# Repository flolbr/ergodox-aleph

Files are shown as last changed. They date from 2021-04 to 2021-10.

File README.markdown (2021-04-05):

# Ergodox Aleph 1

Please note that this project uses the nightly version of KiCad (or Kicad 6).

Ergodox [Aleph 1][aleph] is a modification of the [Ergodox Infinity][original].

Major changes include:

* Full Under-Key RGB
* Through-hole diodes for easy soldering
* Replaced the expensive J-Link Needle port with a cheaper J-Link socket
* RGB header for optional underglow
* Added stabiliser holes to 2U keys on thumb cluster
* Replaced discontinued USB ports with new parts

**I've only done the left board so far.**

[aleph]: https://en.wikipedia.org/wiki/Aleph_number
[original]: https://input.club/devices/infinity-ergodox/

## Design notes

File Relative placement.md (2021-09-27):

Left (d=nok, led=ok):
D36:     (at 69.066497 132.373 180)
LED36: (at 72.241499 127.320001)
S36:      (at 72.241499 132.32 180)
led_x = s_x; led_y = s_y - 5

Right (d=ok, led=nok):
D36:     (at 145.478 140.028 180)
LED36: (at 148.6154 134.366)
S36:      (at 148.59 140.028 180)
d_x = s_x - 3.112; d_y = s_y

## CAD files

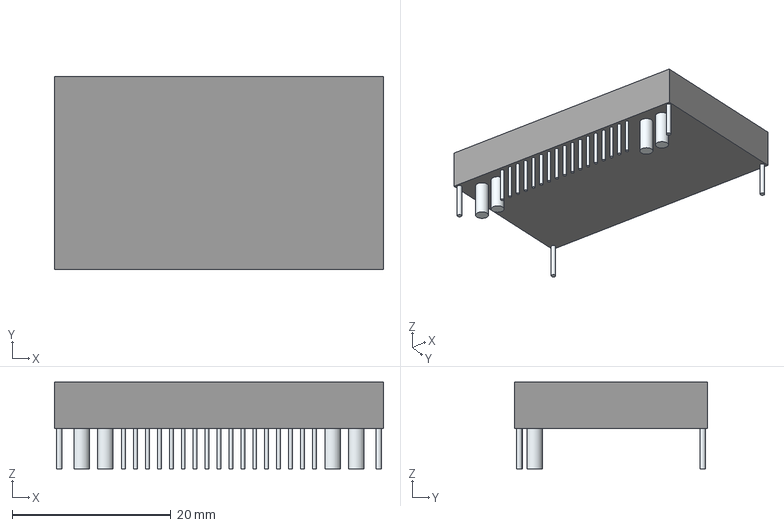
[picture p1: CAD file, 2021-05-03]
ICED - Left/alt3d/NHD-C12832A1Z-FS_RGB_-FBW-3V.stp
41.4 x 24.3 x 10.9 mm
Leads x 25

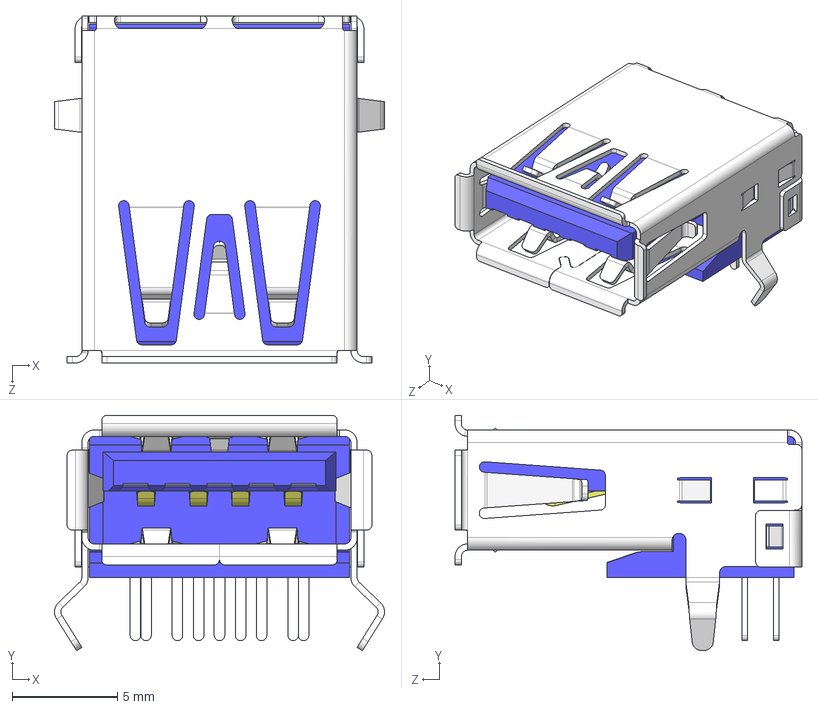
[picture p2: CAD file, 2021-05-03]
ICED - Left/alt3d/CUI_DEVICES_UJ3-AH-4-TH.step
15.7 x 11.2 x 16.5 mm

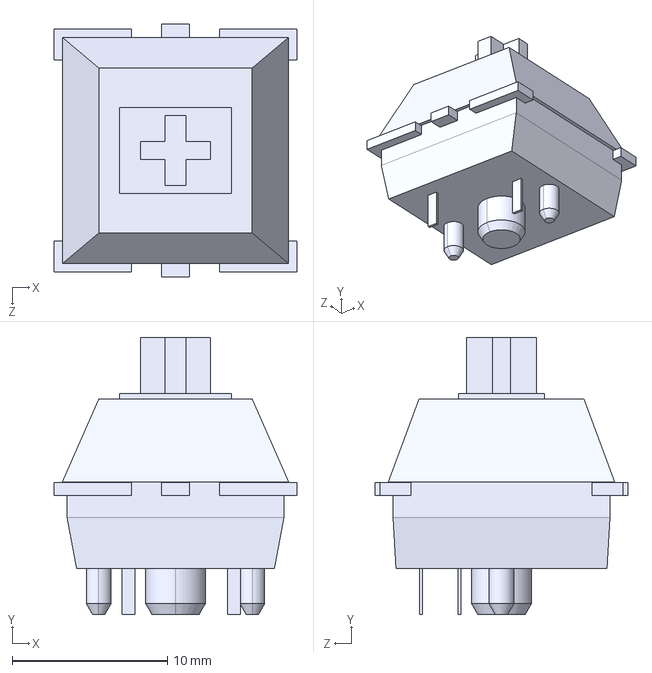
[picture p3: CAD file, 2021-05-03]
ICED - Left/alt3d/cherry mx.STEP
15.6 x 17.9 x 16.3 mm

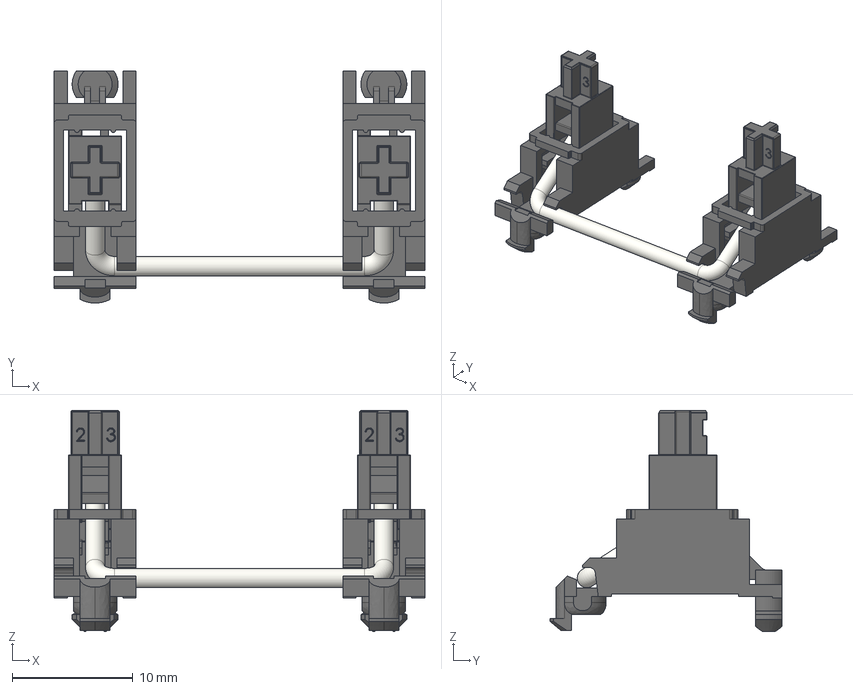
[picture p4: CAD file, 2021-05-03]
ICED - Left/alt3d/Stabilizer_Cherry_MX_2u.step
30.7 x 19.2 x 18.3 mm

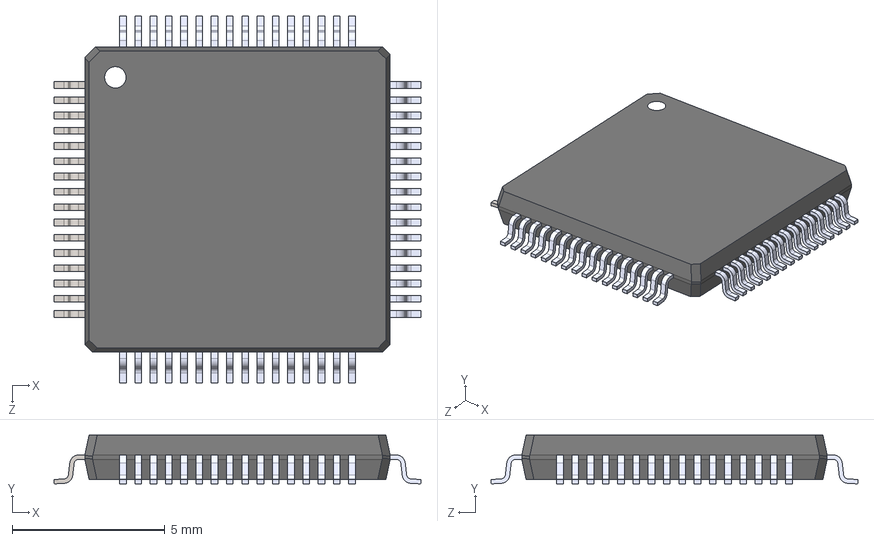
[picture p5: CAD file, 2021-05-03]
ICED - Left/alt3d/MK20DX256VLH7--3DModel-STEP-56544.STEP
12.0 x 1.60 x 12.0 mm

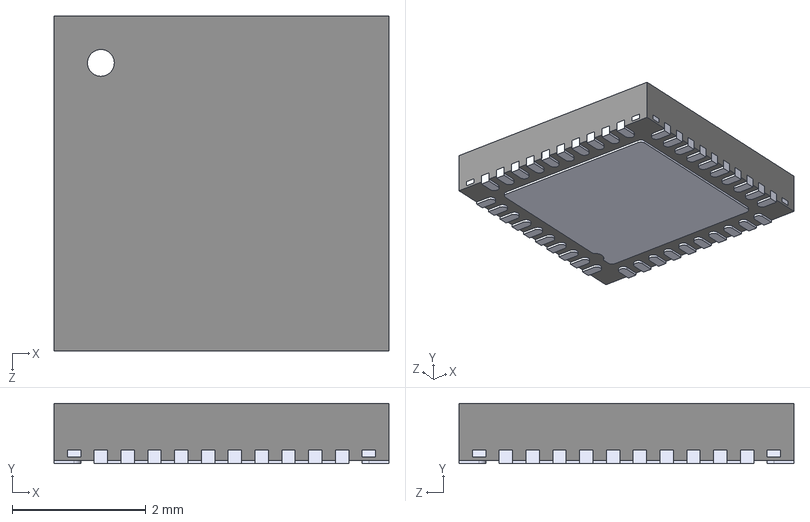
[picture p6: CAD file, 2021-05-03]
ICED - Left/alt3d/DA14586-00F02AT2.STEP
5.00 x 0.9 x 5.00 mm

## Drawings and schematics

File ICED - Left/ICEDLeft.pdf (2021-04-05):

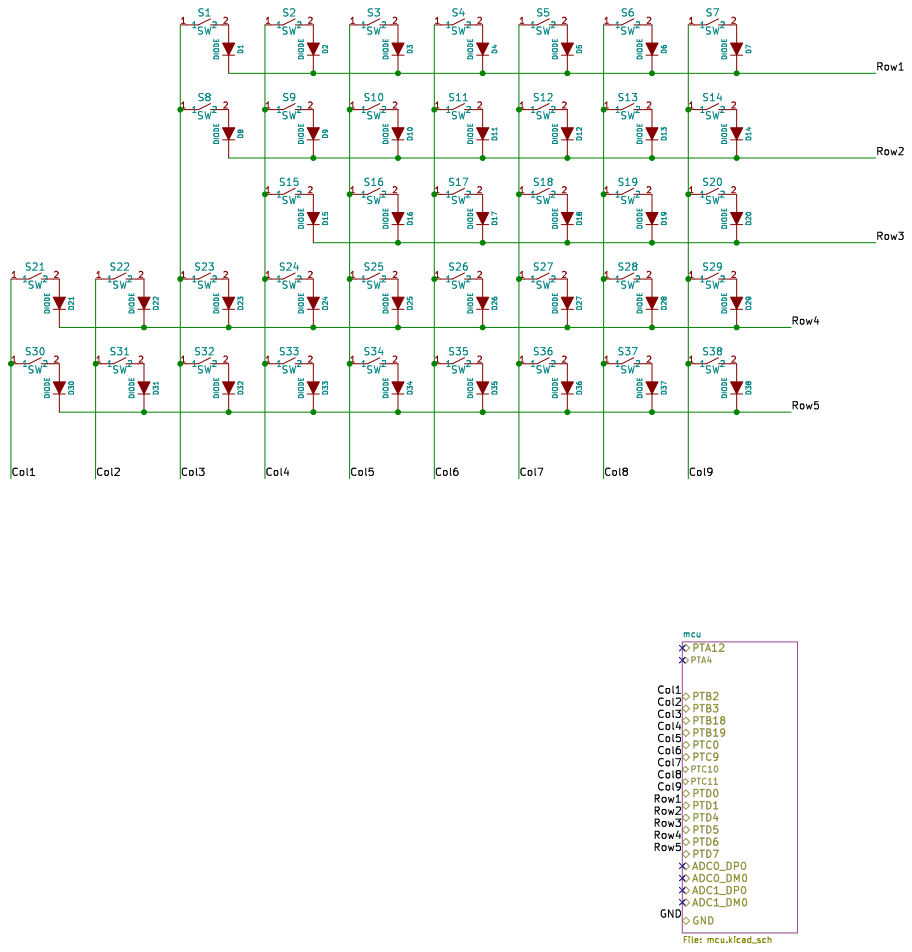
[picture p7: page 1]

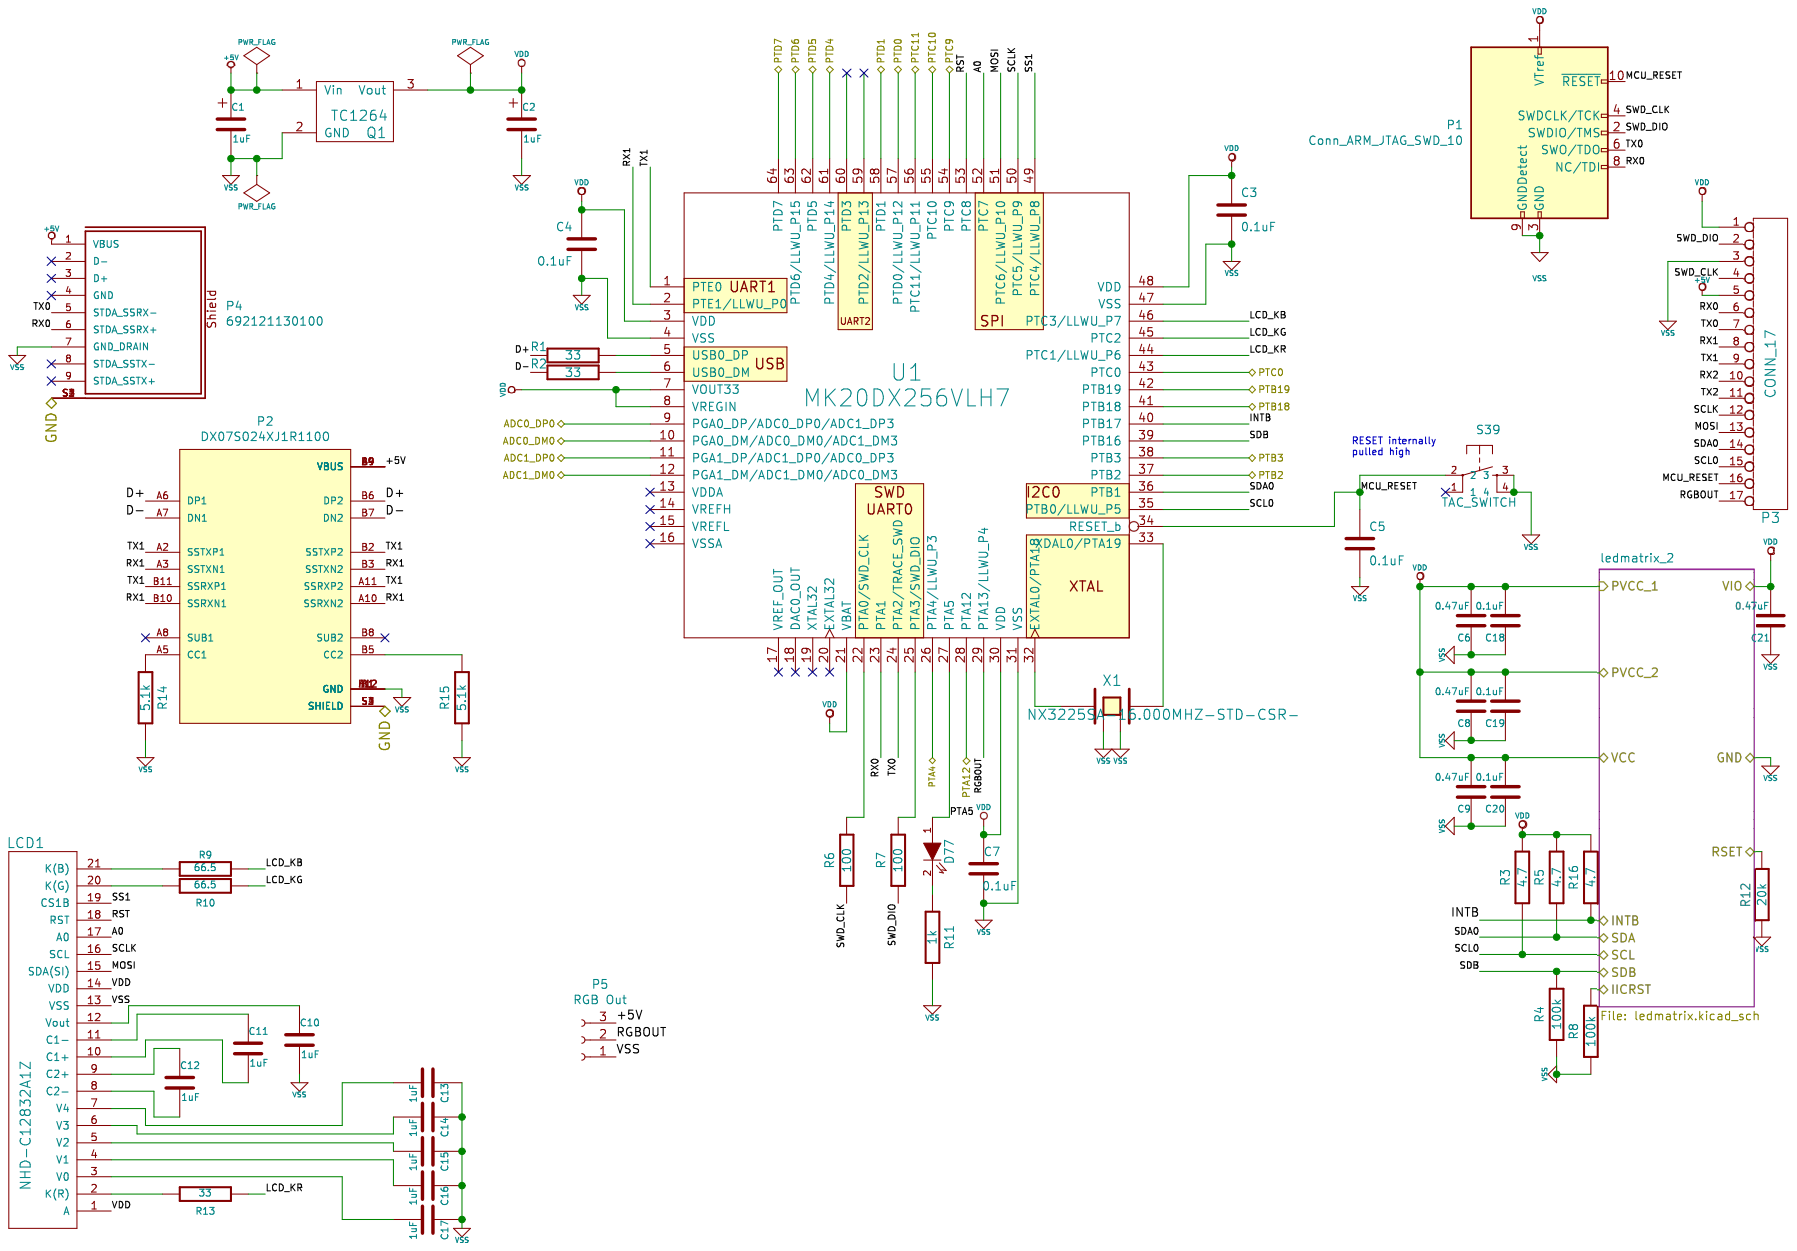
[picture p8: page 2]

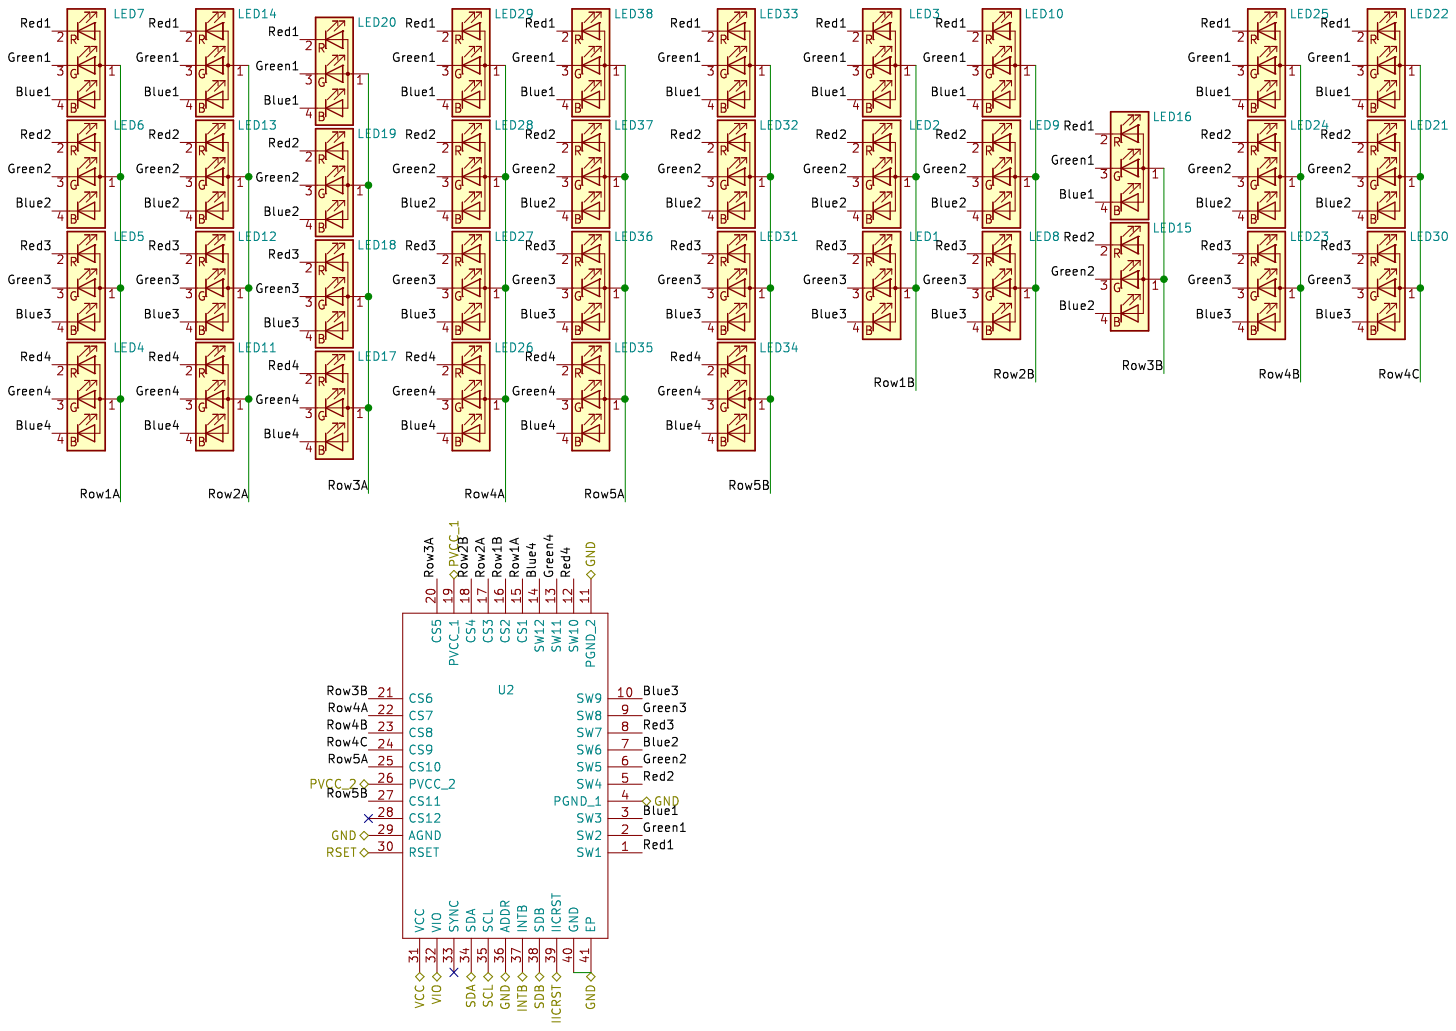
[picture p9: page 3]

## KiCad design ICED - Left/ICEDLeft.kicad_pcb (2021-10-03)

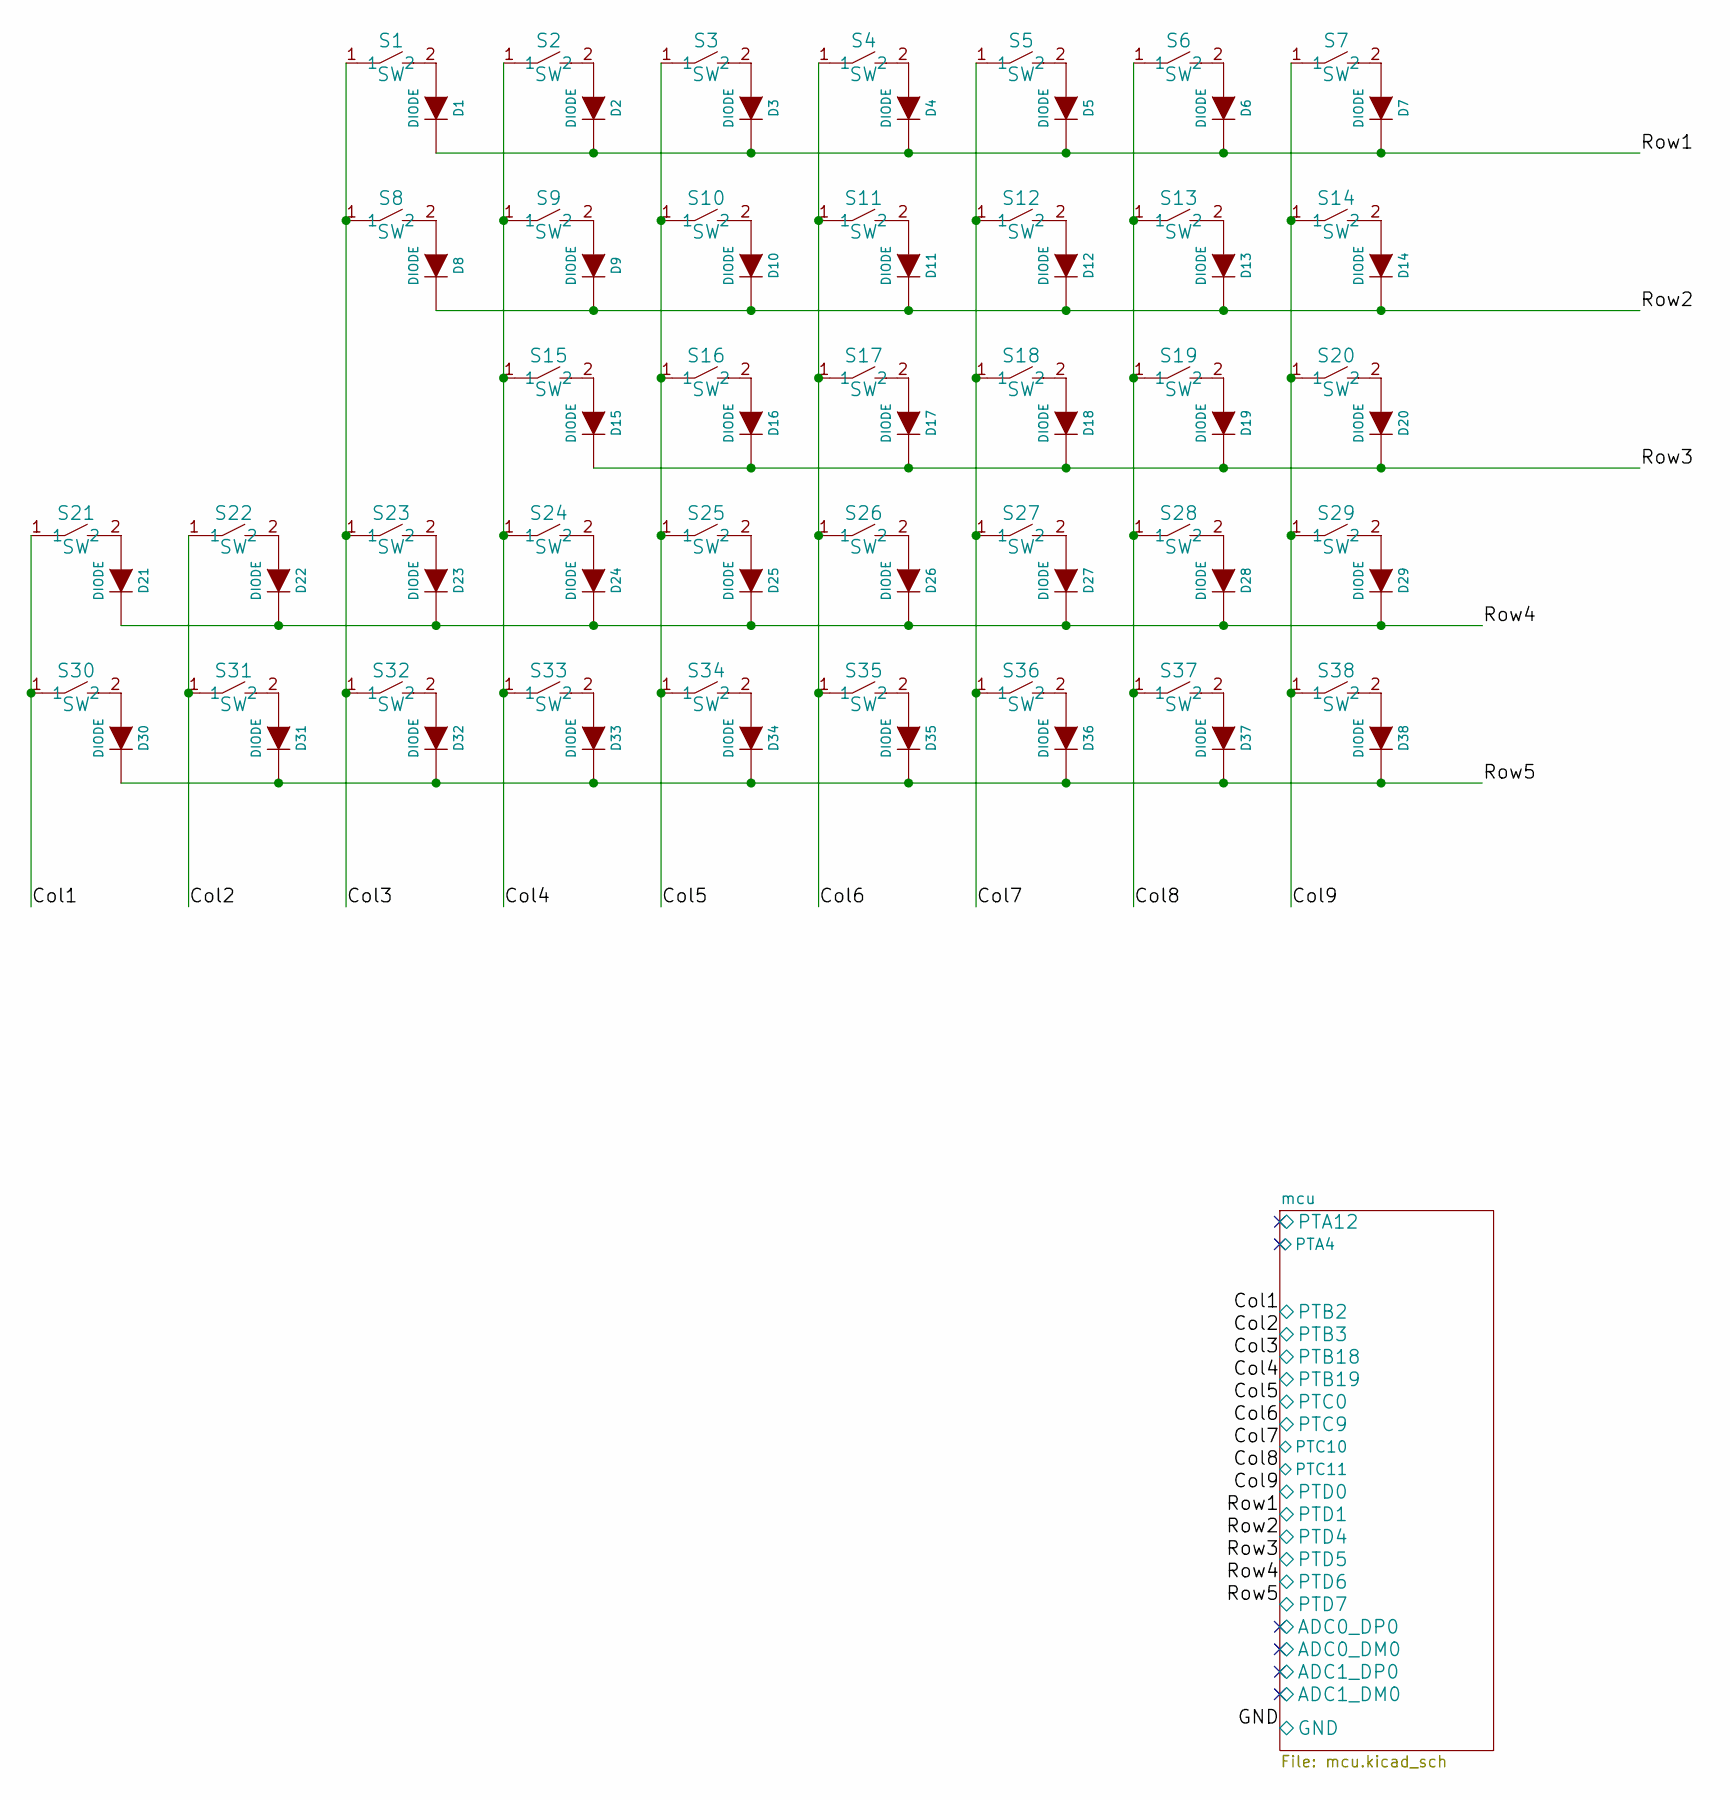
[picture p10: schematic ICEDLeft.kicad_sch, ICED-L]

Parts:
D1, D2, D3, D4, D5, D6, D7, D8, D9, D10, D11, D12, D13, D14, D15, D16, D17, D18, D19, D20, D21, D22, D23, D24, D25, D26, D27, D28, D29, D30, D31, D32, D33, D34, D35, D36, D37, D38: DIODE; SOT123-DIODE
S1, S2, S3, S4, S5, S6, S7, S8, S9, S10, S11, S12, S13, S14, S15, S16, S17, S18, S19, S20, S21, S22, S23, S24, S25, S26, S27, S28, S29, S30, S31, S32, S33, S34, S35, S36, S37, S38: SW; SW_Hotswap_Kailh

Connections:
/Col1: S21.1, S30.1; also elsewhere on the board
/Col2: S22.1, S31.1; also elsewhere on the board
/Col3: S1.1, S8.1, S23.1, S32.1; also elsewhere on the board
/Col4: S2.1, S9.1, S15.1, S24.1, S33.1; also elsewhere on the board
/Col5: S3.1, S10.1, S16.1, S25.1, S34.1; also elsewhere on the board
/Col6: S4.1, S11.1, S17.1, S26.1, S35.1; also elsewhere on the board
/Col7: S5.1, S12.1, S18.1, S27.1, S36.1; also elsewhere on the board
/Col8: S6.1, S13.1, S19.1, S28.1, S37.1; also elsewhere on the board
/Col9: S7.1, S14.1, S20.1, S29.1, S38.1; also elsewhere on the board
/Row1: D1.2 (K), D2.2 (K), D3.2 (K), D4.2 (K), D5.2 (K), D6.2 (K), D7.2 (K); also elsewhere on the board
/Row2: D8.2 (K), D9.2 (K), D10.2 (K), D11.2 (K), D12.2 (K), D13.2 (K), D14.2 (K); also elsewhere on the board
/Row3: D15.2 (K), D16.2 (K), D17.2 (K), D18.2 (K), D19.2 (K), D20.2 (K); also elsewhere on the board
/Row4: D21.2 (K), D22.2 (K), D23.2 (K), D24.2 (K), D25.2 (K), D26.2 (K), D27.2 (K), D28.2 (K), D29.2 (K); also elsewhere on the board
/Row5: D30.2 (K), D31.2 (K), D32.2 (K), D33.2 (K), D34.2 (K), D35.2 (K), D36.2 (K), D37.2 (K), D38.2 (K); also elsewhere on the board
unnamed: D1.1 (A), S1.2
unnamed: D2.1 (A), S2.2
unnamed: D3.1 (A), S3.2
unnamed: D4.1 (A), S4.2
unnamed: D5.1 (A), S5.2
unnamed: D6.1 (A), S6.2
unnamed: D7.1 (A), S7.2
unnamed: D8.1 (A), S8.2
unnamed: D9.1 (A), S9.2
unnamed: D10.1 (A), S10.2
unnamed: D11.1 (A), S11.2
unnamed: D12.1 (A), S12.2
unnamed: D13.1 (A), S13.2
unnamed: D14.1 (A), S14.2
unnamed: D15.1 (A), S15.2
unnamed: D16.1 (A), S16.2
unnamed: D17.1 (A), S17.2
unnamed: D18.1 (A), S18.2
unnamed: D19.1 (A), S19.2
unnamed: D20.1 (A), S20.2
unnamed: D21.1 (A), S21.2
unnamed: D22.1 (A), S22.2
unnamed: D23.1 (A), S23.2
unnamed: D24.1 (A), S24.2
unnamed: D25.1 (A), S25.2
unnamed: D26.1 (A), S26.2
unnamed: D27.1 (A), S27.2
unnamed: D28.1 (A), S28.2
unnamed: D29.1 (A), S29.2
unnamed: D30.1 (A), S30.2
unnamed: D31.1 (A), S31.2
unnamed: D32.1 (A), S32.2
unnamed: D33.1 (A), S33.2
unnamed: D34.1 (A), S34.2
unnamed: D35.1 (A), S35.2
unnamed: D36.1 (A), S36.2
unnamed: D37.1 (A), S37.2
unnamed: D38.1 (A), S38.2

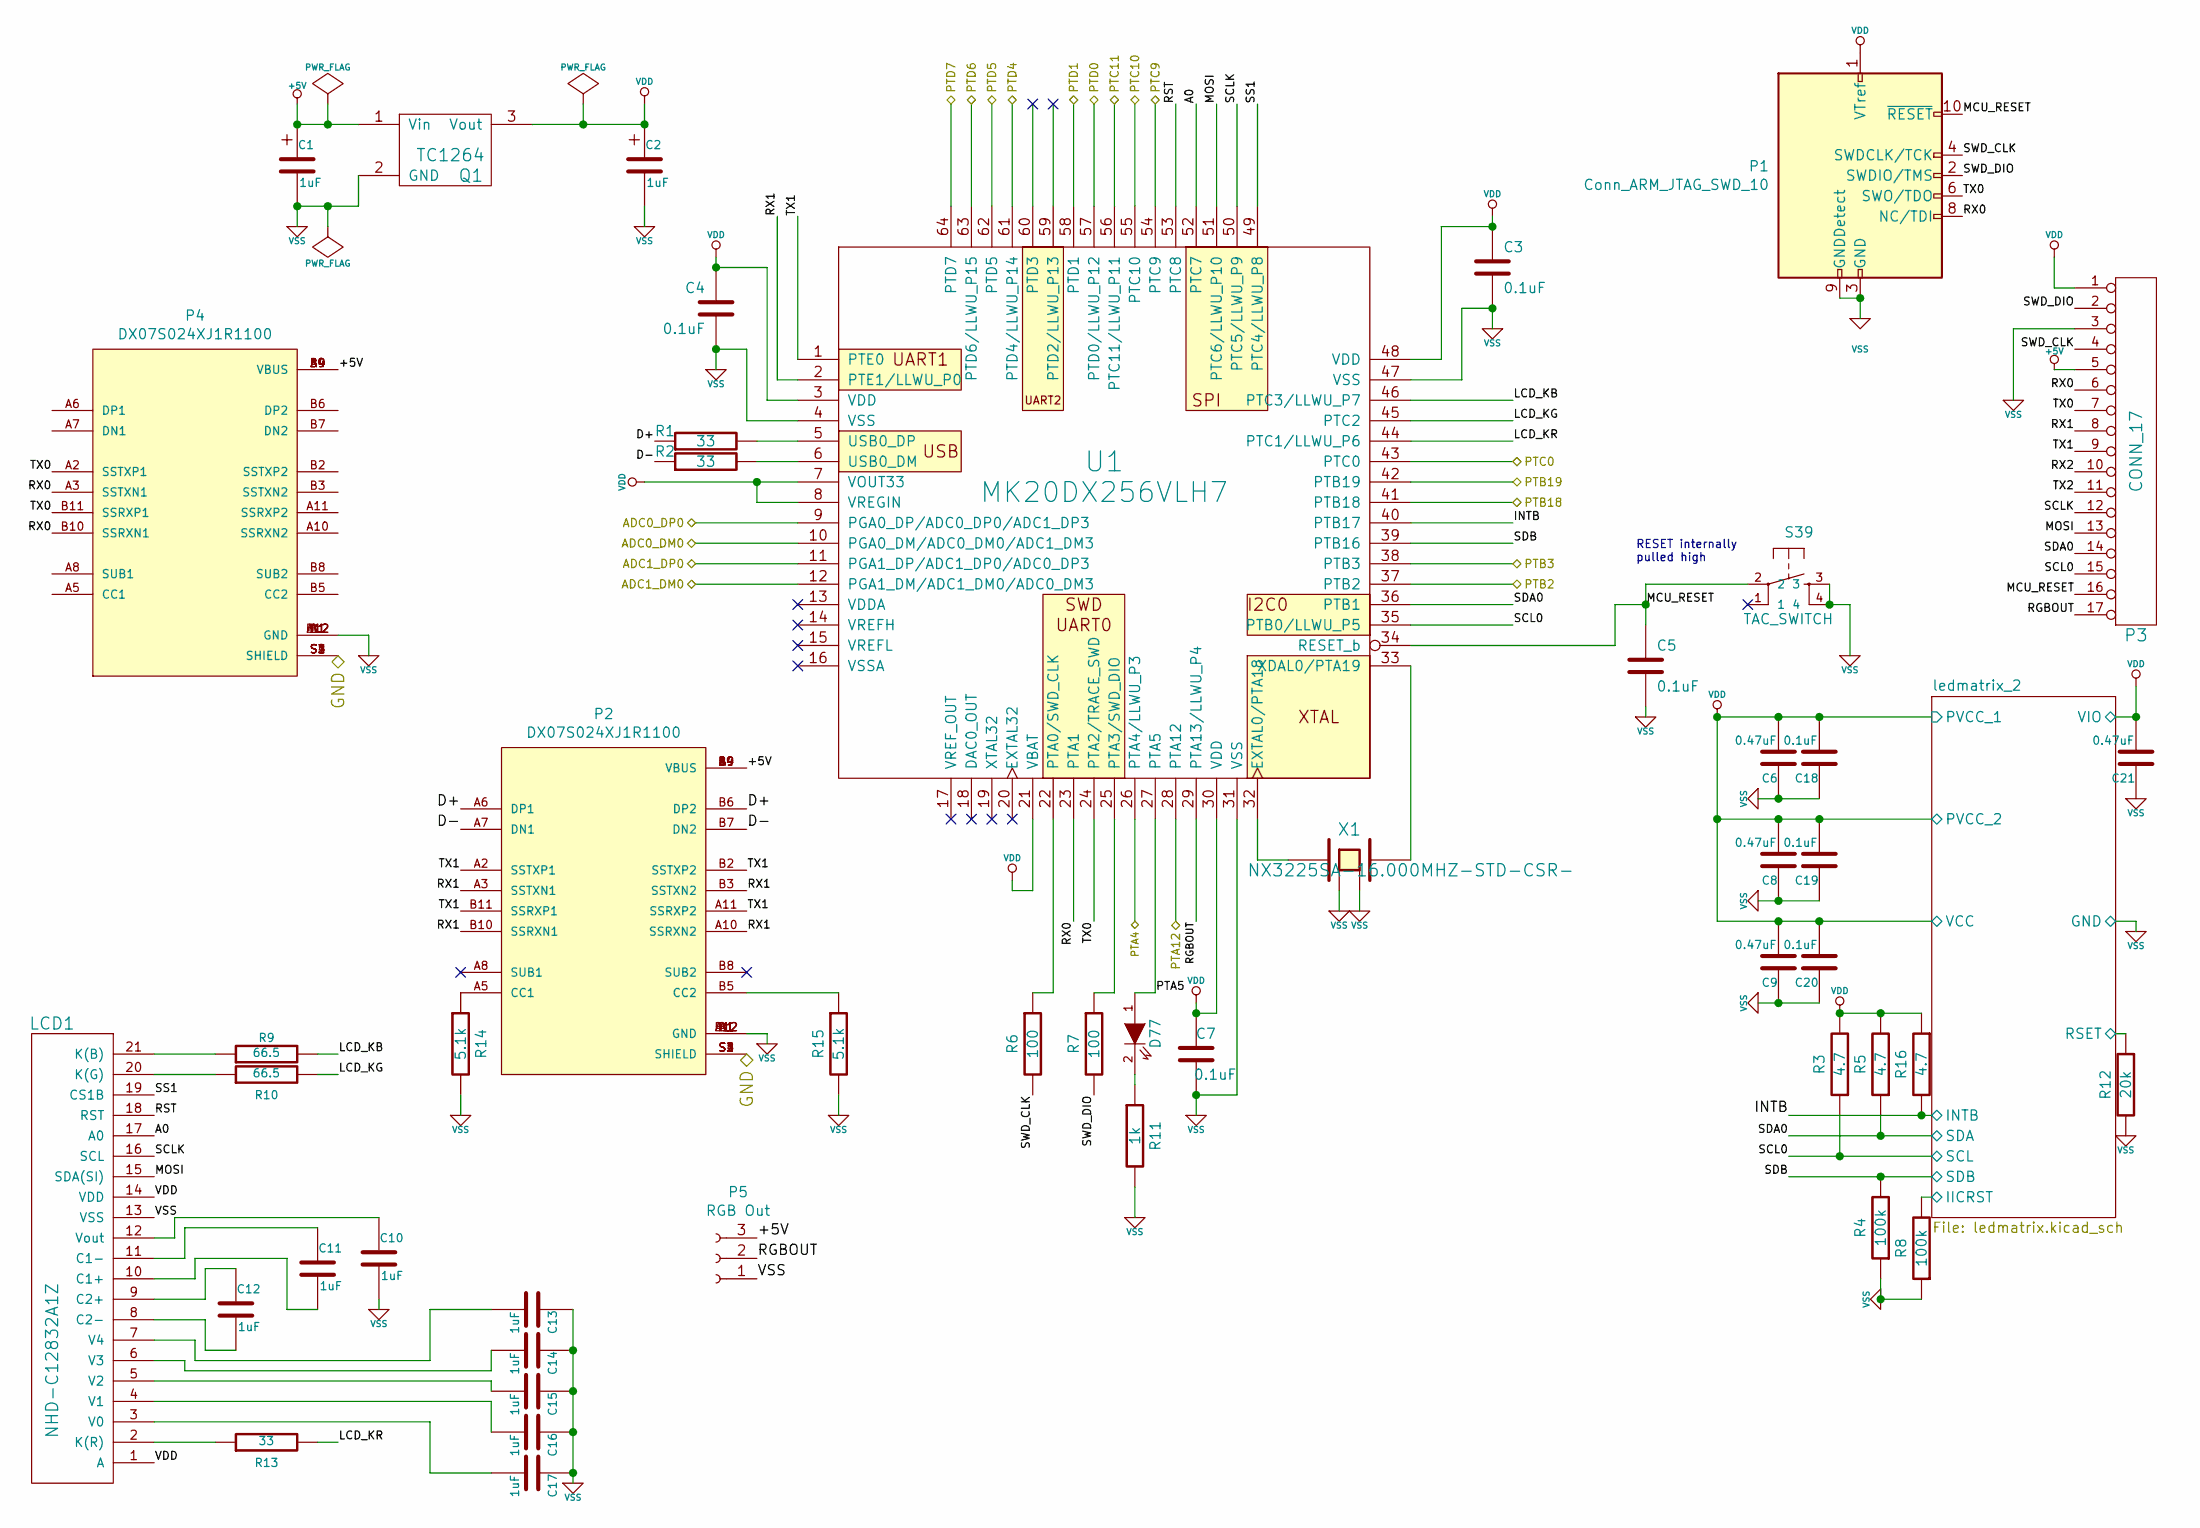
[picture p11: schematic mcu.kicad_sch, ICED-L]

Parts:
C1, C2, C10, C11, C12, C13, C14, C15, C16, C17: 1uF; SMD-1005
C3, C4, C5, C7, C18, C19, C20: 0.1uF; SMD-1005
C6, C8, C9, C21: 0.47uF; SMD-1005
D77: LED; LED-0603
LCD1: NHD-C12832A1Z
P1: Conn_ARM_JTAG_SWD_10; SHF-105-01-L-D-TH
P2, P4: DX07S024XJ1R1100; JAE_DX07S024XJ1R1100; PARTREV 1
P3: CONN_17; HEADER_1x17
P5: RGB Out; PinHeader_1x03_P2.54mm_Horizontal
Q1: TC1264; SOT-223
R1, R2, R13: 33; SMD-1005
R3, R5, R16: 4.7; SMD-1005
R4, R8: 100k; SMD-1005
R6, R7: 100; SMD-1005
R9, R10: 66.5; SMD-1005
R11: 1k; SMD-1005
R12: 20k; SMD-1005
R14, R15: 5.1k; SMD-1005
S39: TAC_SWITCH; TACT_5.2x5.2
U1: MK20DX256VLH7; LQFP64
X1: NX3225SA-16.000MHZ-STD-CSR-; NX3225SA

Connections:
+5V: C1.1, P2.A4 (VBUS), P2.A9 (VBUS), P2.B4 (VBUS), P2.B9 (VBUS), P3.5, P4.A4 (VBUS), P4.A9 (VBUS), P4.B4 (VBUS), P4.B9 (VBUS), P5.3, Q1.1 (Vin)
/Col1: U1.37 (PTB2); also elsewhere on the board
/Col2: U1.38 (PTB3); also elsewhere on the board
/Col3: U1.41 (PTB18); also elsewhere on the board
/Col4: U1.42 (PTB19); also elsewhere on the board
/Col5: U1.43 (PTC0); also elsewhere on the board
/Col6: U1.54 (PTC9); also elsewhere on the board
/Col7: U1.55 (PTC10); also elsewhere on the board
/Col8: U1.56 (PTC11/LLWU_P11); also elsewhere on the board
/Col9: U1.57 (PTD0/LLWU_P12); also elsewhere on the board
/GND: P2.S1 (SHIELD), P2.S2 (SHIELD), P2.S3 (SHIELD), P2.S4 (SHIELD), P4.S1 (SHIELD), P4.S2 (SHIELD), P4.S3 (SHIELD), P4.S4 (SHIELD)
/Row1: U1.58 (PTD1); also elsewhere on the board
/Row2: U1.61 (PTD4/LLWU_P14); also elsewhere on the board
/Row3: U1.62 (PTD5); also elsewhere on the board
/Row4: U1.63 (PTD6/LLWU_P15); also elsewhere on the board
/Row5: U1.64 (PTD7); also elsewhere on the board
/mcu/A0: LCD1.17 (A0), U1.52 (PTC7)
/mcu/ADC0_DM0: U1.10 (PGA0_DM/ADC0_DM0/ADC1_DM3)
/mcu/ADC0_DP0: U1.9 (PGA0_DP/ADC0_DP0/ADC1_DP3)
/mcu/ADC1_DM0: U1.12 (PGA1_DM/ADC1_DM0/ADC0_DM3)
/mcu/ADC1_DP0: U1.11 (PGA1_DP/ADC1_DP0/ADC0_DP3)
/mcu/D+: P2.A6 (DP1), P2.B6 (DP2), R1.1
/mcu/D-: P2.A7 (DN1), P2.B7 (DN2), R2.1
/mcu/INTB: R16.2, U1.40 (PTB17); also elsewhere on the board
/mcu/LCD_KB: R9.2, U1.46 (PTC3/LLWU_P7)
/mcu/LCD_KG: R10.2, U1.45 (PTC2)
/mcu/LCD_KR: R13.2, U1.44 (PTC1/LLWU_P6)
/mcu/MCU_RESET: C5.1, P1.10 (~RESET), P3.16, S39.2, U1.34 (RESET_b)
/mcu/MOSI: LCD1.15 (SDA(SI)), P3.13, U1.51 (PTC6/LLWU_P10)
/mcu/PTA4: U1.26 (PTA4/LLWU_P3)
/mcu/PTA5: D77.1 (A), U1.27 (PTA5)
/mcu/PTA12: U1.28 (PTA12)
/mcu/RGBOUT: P3.17, P5.2, U1.29 (PTA13/LLWU_P4)
/mcu/RST: LCD1.18 (RST), U1.53 (PTC8)
/mcu/RX0: P1.8 (NC/TDI), P3.6, P4.A3 (SSTXN1), P4.B10 (SSRXN1), U1.23 (PTA1)
/mcu/RX1: P2.A3 (SSTXN1), P2.A10 (SSRXN2), P2.B3 (SSTXN2), P2.B10 (SSRXN1), P3.8, U1.2 (PTE1/LLWU_P0)
/mcu/RX2: P3.10
/mcu/SCL0: P3.15, R3.1, U1.35 (PTB0/LLWU_P5); also elsewhere on the board
/mcu/SCLK: LCD1.16 (SCL), P3.12, U1.50 (PTC5/LLWU_P9)
/mcu/SDA0: P3.14, R5.1, U1.36 (PTB1); also elsewhere on the board
/mcu/SDB: R4.2, U1.39 (PTB16); also elsewhere on the board
/mcu/SS1: LCD1.19 (CS1B), U1.49 (PTC4/LLWU_P8)
/mcu/SWD_CLK: P1.4 (SWDCLK/TCK), P3.4, R6.2
/mcu/SWD_DIO: P1.2 (SWDIO/TMS), P3.2, R7.2
/mcu/TX0: P1.6 (SWO/TDO), P3.7, P4.A2 (SSTXP1), P4.B11 (SSRXP1), U1.24 (PTA2/TRACE_SWD)
/mcu/TX1: P2.A2 (SSTXP1), P2.A11 (SSRXP2), P2.B2 (SSTXP2), P2.B11 (SSRXP1), P3.9, U1.1 (PTE0)
/mcu/TX2: P3.11
/mcu/ledmatrix_2/IICRST: R8.2; also elsewhere on the board
/mcu/ledmatrix_2/RSET: R12.1; also elsewhere on the board
unnamed: C10.1, LCD1.12 (Vout)
unnamed: C11.1, LCD1.11 (C1-)
unnamed: C11.2, LCD1.10 (C1+)
unnamed: C12.1, LCD1.9 (C2+)
unnamed: C12.2, LCD1.8 (C2-)
unnamed: C13.2, LCD1.7 (V4)
unnamed: C14.2, LCD1.6 (V3)
unnamed: C15.2, LCD1.5 (V2)
unnamed: C16.2, LCD1.4 (V1)
unnamed: C17.2, LCD1.3 (V0)
unnamed: D77.2 (K), R11.1
unnamed: LCD1.2 (K(R)), R13.1
unnamed: LCD1.20 (K(G)), R10.1
unnamed: LCD1.21 (K(B)), R9.1
unnamed: R1.2, U1.5 (USB0_DP)
unnamed: R2.2, U1.6 (USB0_DM)
unnamed: R6.1, U1.22 (PTA0/SWD_CLK)
unnamed: R7.1, U1.25 (PTA3/SWD_DIO)
unnamed: P2.A5 (CC1), R14.1
unnamed: P2.B5 (CC2), R15.1
unnamed: U1.32 (EXTAL0/PTA18), X1.1
unnamed: U1.33 (XDAL0/PTA19), X1.3
VDD: C2.1, C3.1, C4.1, C6.2, C7.1, C8.2, C9.2, C18.2, C19.2, C20.2, C21.2, LCD1.1 (A), LCD1.14 (VDD), P1.1 (VTref), P3.1, Q1.3 (Vout), R3.2, R5.2, R16.1, U1.3 (VDD), U1.7 (VOUT33), U1.8 (VREGIN), U1.21 (VBAT), U1.30 (VDD), U1.48 (VDD); also elsewhere on the board
VSS: C1.2, C2.2, C3.2, C4.2, C5.2, C6.1, C7.2, C8.1, C9.1, C10.2, C13.1, C14.1, C15.1, C16.1, C17.1, C18.1, C19.1, C20.1, C21.1, LCD1.13 (VSS), P1.3 (GND), P1.5 (GND), P1.9 (GNDDetect), P2.A1 (GND), P2.A12 (GND), P2.B1 (GND), P2.B12 (GND), P3.3, P4.A1 (GND), P4.A12 (GND), P4.B1 (GND), P4.B12 (GND), P5.1, Q1.2 (GND), R4.1, R8.1, R11.2, R12.2, R14.2, R15.2, S39.3, S39.4, U1.4 (VSS), U1.31 (VSS), U1.47 (VSS), X1.2, X1.4; also elsewhere on the board

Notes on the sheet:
RESET internally pulled high

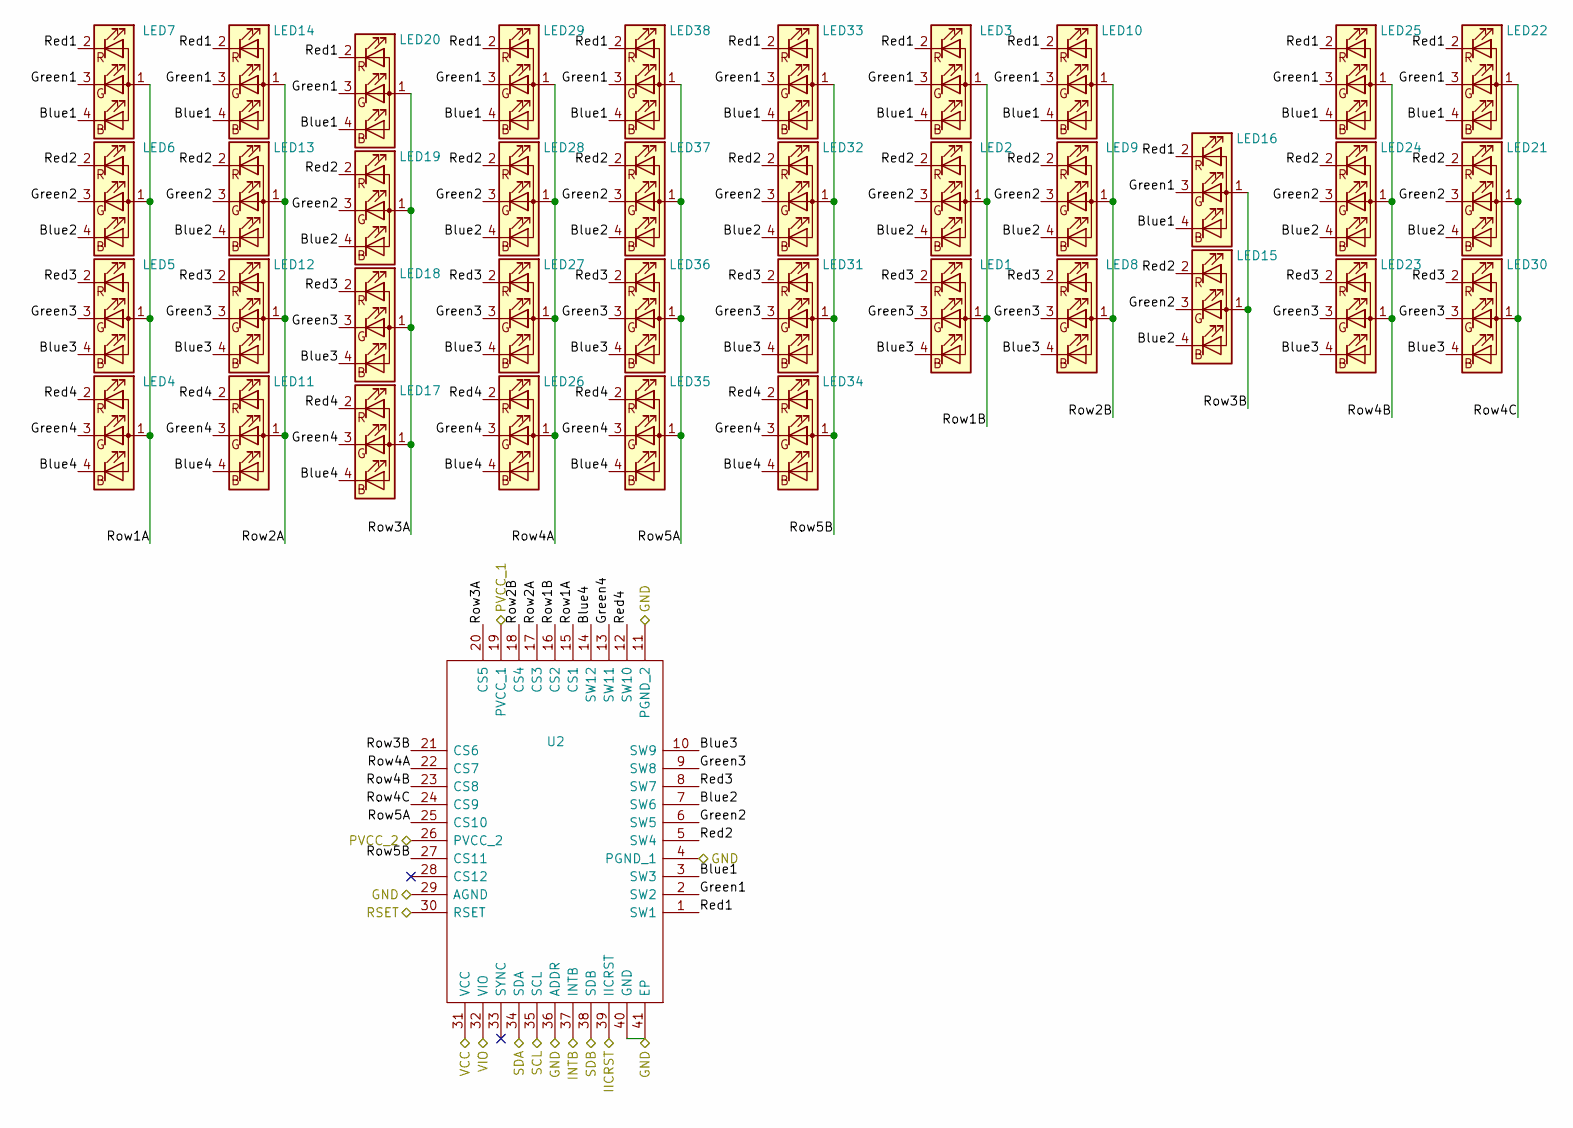
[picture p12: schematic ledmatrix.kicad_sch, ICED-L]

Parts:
LED1, LED2, LED3, LED4, LED5, LED6, LED7, LED8, LED9, LED10, LED11, LED12, LED13, LED14, LED15, LED16, LED17, LED18, LED19, LED20, LED21, LED22, LED23, LED24, LED25, LED26, LED27, LED28, LED29, LED30, LED31, LED32, LED33, LED34, LED35, LED36, LED37, LED38: RGB_0606; 0606
U2: IS31FL3737-QFLS4-TR; QFN40P500X500X80-41N-D; Manufacturer_Part_Number IS31FL3737-QFLS4-TR; Mouser Part Number 870-31FL3737QFLS4TR

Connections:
/mcu/INTB: U2.37 (INTB); also elsewhere on the board
/mcu/SCL0: U2.35 (SCL); also elsewhere on the board
/mcu/SDA0: U2.34 (SDA); also elsewhere on the board
/mcu/SDB: U2.38 (SDB); also elsewhere on the board
/mcu/ledmatrix_2/Blue1: LED3.4 (BK), LED7.4 (BK), LED10.4 (BK), LED14.4 (BK), LED16.4 (BK), LED20.4 (BK), LED22.4 (BK), LED25.4 (BK), LED29.4 (BK), LED33.4 (BK), LED38.4 (BK), U2.3 (SW3)
/mcu/ledmatrix_2/Blue2: LED2.4 (BK), LED6.4 (BK), LED9.4 (BK), LED13.4 (BK), LED15.4 (BK), LED19.4 (BK), LED21.4 (BK), LED24.4 (BK), LED28.4 (BK), LED32.4 (BK), LED37.4 (BK), U2.7 (SW6)
/mcu/ledmatrix_2/Blue3: LED1.4 (BK), LED5.4 (BK), LED8.4 (BK), LED12.4 (BK), LED18.4 (BK), LED23.4 (BK), LED27.4 (BK), LED30.4 (BK), LED31.4 (BK), LED36.4 (BK), U2.10 (SW9)
/mcu/ledmatrix_2/Blue4: LED4.4 (BK), LED11.4 (BK), LED17.4 (BK), LED26.4 (BK), LED34.4 (BK), LED35.4 (BK), U2.14 (SW12)
/mcu/ledmatrix_2/Green1: LED3.3 (GK), LED7.3 (GK), LED10.3 (GK), LED14.3 (GK), LED16.3 (GK), LED20.3 (GK), LED22.3 (GK), LED25.3 (GK), LED29.3 (GK), LED33.3 (GK), LED38.3 (GK), U2.2 (SW2)
/mcu/ledmatrix_2/Green2: LED2.3 (GK), LED6.3 (GK), LED9.3 (GK), LED13.3 (GK), LED15.3 (GK), LED19.3 (GK), LED21.3 (GK), LED24.3 (GK), LED28.3 (GK), LED32.3 (GK), LED37.3 (GK), U2.6 (SW5)
/mcu/ledmatrix_2/Green3: LED1.3 (GK), LED5.3 (GK), LED8.3 (GK), LED12.3 (GK), LED18.3 (GK), LED23.3 (GK), LED27.3 (GK), LED30.3 (GK), LED31.3 (GK), LED36.3 (GK), U2.9 (SW8)
/mcu/ledmatrix_2/Green4: LED4.3 (GK), LED11.3 (GK), LED17.3 (GK), LED26.3 (GK), LED34.3 (GK), LED35.3 (GK), U2.13 (SW11)
/mcu/ledmatrix_2/IICRST: U2.39 (IICRST); also elsewhere on the board
/mcu/ledmatrix_2/RSET: U2.30 (RSET); also elsewhere on the board
/mcu/ledmatrix_2/Red1: LED3.2 (RK), LED7.2 (RK), LED10.2 (RK), LED14.2 (RK), LED16.2 (RK), LED20.2 (RK), LED22.2 (RK), LED25.2 (RK), LED29.2 (RK), LED33.2 (RK), LED38.2 (RK), U2.1 (SW1)
/mcu/ledmatrix_2/Red2: LED2.2 (RK), LED6.2 (RK), LED9.2 (RK), LED13.2 (RK), LED15.2 (RK), LED19.2 (RK), LED21.2 (RK), LED24.2 (RK), LED28.2 (RK), LED32.2 (RK), LED37.2 (RK), U2.5 (SW4)
/mcu/ledmatrix_2/Red3: LED1.2 (RK), LED5.2 (RK), LED8.2 (RK), LED12.2 (RK), LED18.2 (RK), LED23.2 (RK), LED27.2 (RK), LED30.2 (RK), LED31.2 (RK), LED36.2 (RK), U2.8 (SW7)
/mcu/ledmatrix_2/Red4: LED4.2 (RK), LED11.2 (RK), LED17.2 (RK), LED26.2 (RK), LED34.2 (RK), LED35.2 (RK), U2.12 (SW10)
/mcu/ledmatrix_2/Row1A: LED4.1 (A), LED5.1 (A), LED6.1 (A), LED7.1 (A), U2.15 (CS1)
/mcu/ledmatrix_2/Row1B: LED1.1 (A), LED2.1 (A), LED3.1 (A), U2.16 (CS2)
/mcu/ledmatrix_2/Row2A: LED11.1 (A), LED12.1 (A), LED13.1 (A), LED14.1 (A), U2.17 (CS3)
/mcu/ledmatrix_2/Row2B: LED8.1 (A), LED9.1 (A), LED10.1 (A), U2.18 (CS4)
/mcu/ledmatrix_2/Row3A: LED17.1 (A), LED18.1 (A), LED19.1 (A), LED20.1 (A), U2.20 (CS5)
/mcu/ledmatrix_2/Row3B: LED15.1 (A), LED16.1 (A), U2.21 (CS6)
/mcu/ledmatrix_2/Row4A: LED26.1 (A), LED27.1 (A), LED28.1 (A), LED29.1 (A), U2.22 (CS7)
/mcu/ledmatrix_2/Row4B: LED23.1 (A), LED24.1 (A), LED25.1 (A), U2.23 (CS8)
/mcu/ledmatrix_2/Row4C: LED21.1 (A), LED22.1 (A), LED30.1 (A), U2.24 (CS9)
/mcu/ledmatrix_2/Row5A: LED35.1 (A), LED36.1 (A), LED37.1 (A), LED38.1 (A), U2.25 (CS10)
/mcu/ledmatrix_2/Row5B: LED31.1 (A), LED32.1 (A), LED33.1 (A), LED34.1 (A), U2.27 (CS11)
VDD: U2.19 (PVCC_1), U2.26 (PVCC_2), U2.31 (VCC), U2.32 (VIO); also elsewhere on the board
VSS: U2.4 (PGND_1), U2.11 (PGND_2), U2.29 (AGND), U2.36 (ADDR), U2.40 (GND), U2.41 (EP); also elsewhere on the board

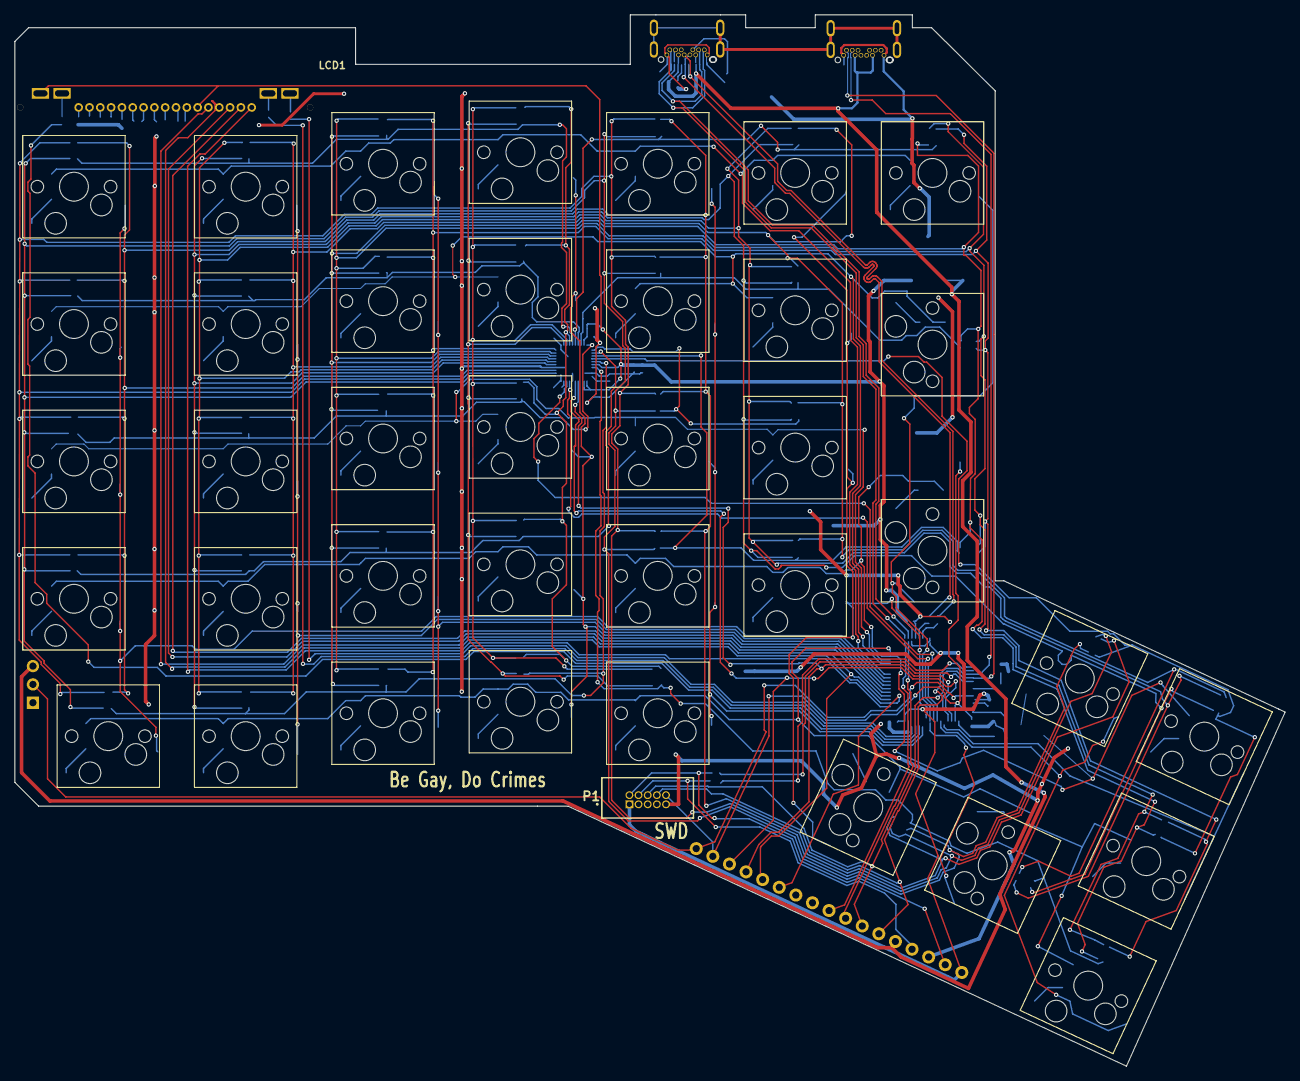
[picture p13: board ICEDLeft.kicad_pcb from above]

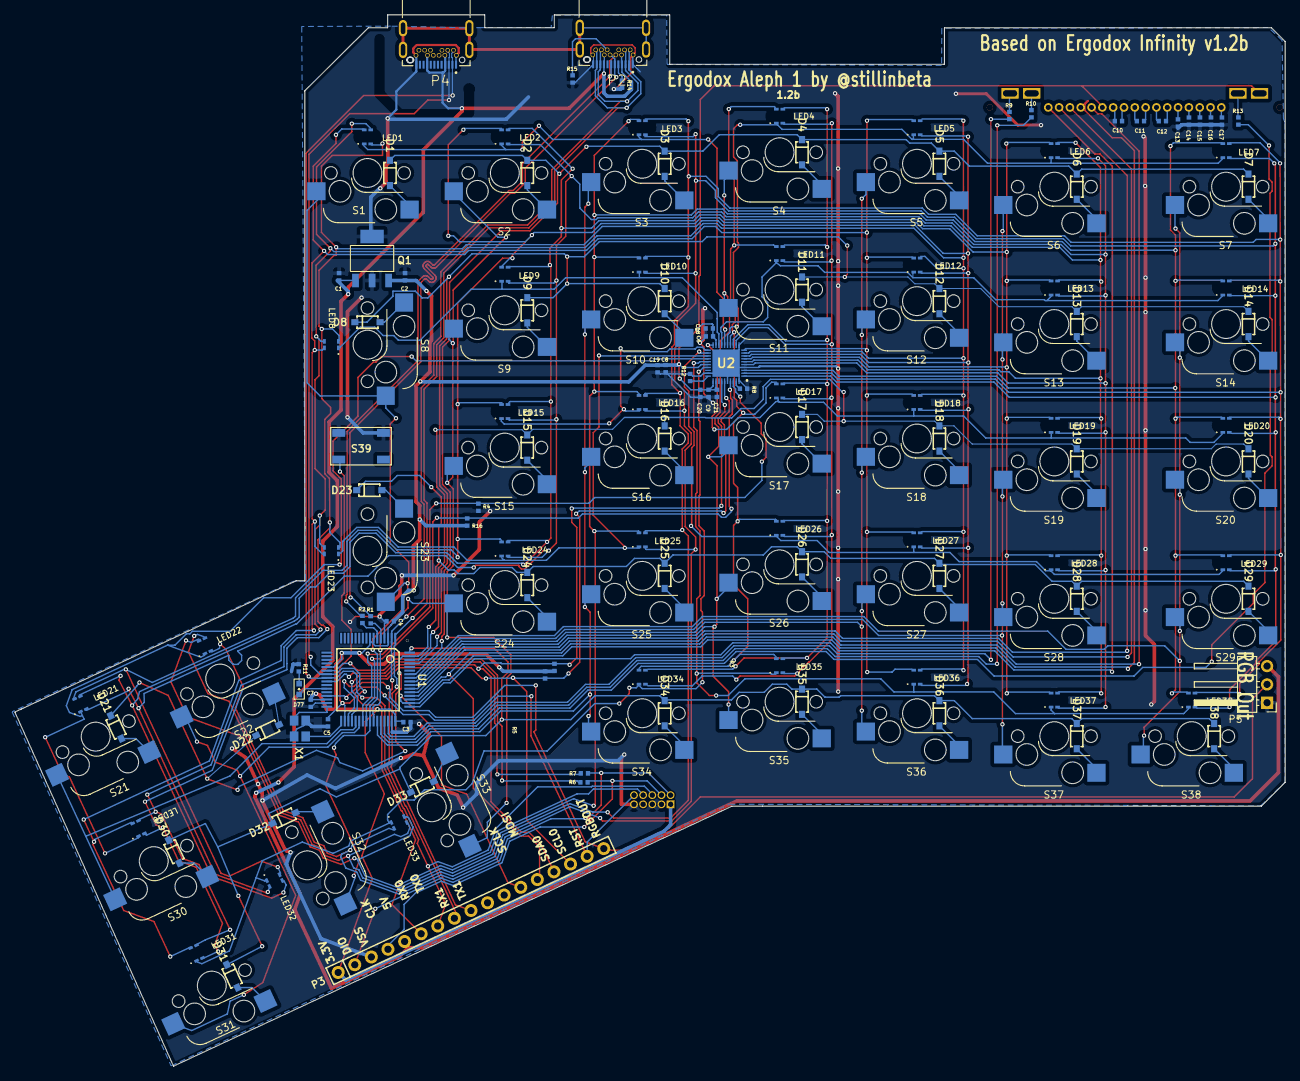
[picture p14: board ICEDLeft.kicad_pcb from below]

Board: 2 copper layers, 176.2 x 145.8 mm, 163 parts (123 on the bottom side), 126 nets.

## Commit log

2021-03-15 RGB LEDs
    [ICEDLeft.sch, mcu.sch]
2021-03-16 Finished laying out components
    [ICEDLeft.kicad_pcb, ICEDLeft.sch, ledmatrix.sch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]
2021-03-17 routed and DRC'd
    [ICEDLeft.kicad_pcb, ICEDLeft.sch, mcu.sch]
2021-03-18 RGB headers and finishing touches!
    [ICEDLeft.kicad_pcb, ICEDLeft.sch, ledmatrix.sch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]
2021-03-18 Remove other projects
    [IC60-B.Mask.gbs, IC60-B.Paste.gbp, IC60-B.SilkS.gbo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]
2021-03-19 Ignore the Gerbers
    [ICEDLeft-B.Mask.gbs, ICEDLeft-B.Paste.gbp, ICEDLeft-B.SilkS.gbo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]
2021-03-19 LED Matrix Connected
    [ledmatrix.sch]
2021-03-19 Footprints placed
    [ICEDLeft.kicad_pcb, ICEDLeft.sch, ledmatrix.sch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]
2021-03-20 Added support caps
    [ICEDLeft.kicad_pcb, ICEDLeft.sch, ledmatrix.sch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]
2021-03-20 left 50% routed
    [ICEDLeft.kicad_pcb, ledmatrix.sch, mcu.sch]
2021-03-20 Routed new USB ports
    [ICEDLeft.kicad_pcb, mcu.sch]
2021-03-20 Cleaned up DRC issues
    [ICEDLeft.kicad_pcb, ICEDLeft.sch, mcu.sch]
2021-03-21 More routing
    [ICEDLeft.kicad_pcb, ledmatrix.sch, mcu.sch]
2021-03-21 Most non-thumb routing finished
    [ICEDLeft.kicad_pcb, ledmatrix.sch]
2021-03-22 Routed and DRC passes
    [ICEDLeft.kicad_pcb, ICEDLeft.sch, ledmatrix.sch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]
2021-03-22 re-added RGBOUT
    [ICEDLeft.kicad_pcb, ICEDLeft.sch, ledmatrix.sch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]
2021-03-22 tweaks and cleanup
    [ICEDLeft.kicad_pcb, mcu.sch]
2021-03-22 even more final tweaks
    [ICEDLeft.kicad_pcb, ICEDLeft.sch, mcu.sch]
2021-03-23 Kailh hotswaps and ground plane
    [ICEDLeft.kicad_pcb, mcu.sch]
2021-03-24 0606 LEDs
    [ICEDLeft.kicad_pcb, ledmatrix.sch]
2021-03-28 Routed correctly
    [ICEDLeft.kicad_pcb, ledmatrix.sch, mcu.sch]
2021-03-28 move RGB header to left side
    [ICEDLeft.kicad_pcb, mcu.sch]
2021-03-30 are you not done tweaking
    [ICEDLeft.kicad_pcb, ICEDLeft.sch, ledmatrix.sch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]
2021-04-02 set jcl design constraints
    [ICEDLeft.kicad_pcb]
2021-04-02 No DRC violations!
    [ICEDLeft.kicad_pcb]
2021-04-03 Routing WIP
    [ICEDLeft.kicad_pcb]
2021-04-04 Routing WIP2
    [ICEDLeft.kicad_pcb]
2021-04-05 50 nets to go
    [ICEDLeft.kicad_pcb]
2021-04-05 Migrate schematics and more routing
    [ICEDLeft.kicad_pcb, ICEDLeft.kicad_sch, ICEDLeft.sch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]
2021-04-05 mostly routed
    [ICEDLeft.kicad_pcb, mcu.kicad_sch]
2021-04-05 Second Revision Finalised
    [ICEDLeft.kicad_pcb, mcu.kicad_sch]
2021-04-05 Add Kicad 6 note
2021-04-05 Reorganized footprints
2021-04-05 Updated schematic PDF
2021-04-05 Replaced BOM
2021-04-11 freecad case wip
    [ICEDLeft.kicad_pcb]
2021-04-12 more case WIP
2021-04-16 even more case WIP
2021-05-03 Add some 3D models
    [CUI_DEVICES_UJ3-AH-4-TH.step, DA14586-00F02AT2.STEP, ICEDLeft.kicad_pcb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]
2021-05-03 tweak values
    [ICEDLeft.kicad_pcb]
2021-09-25 Upgrade project + Right changes
    - Replace MXALPS sockets by Kailh Hot-swaps
    - Replace the LED controller
    [ICEDRight-2021-09-25-10-48-57.sch, ICEDRight.kicad_pcb, ICEDRight.kicad_sch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]
2021-09-25 Place all LEDs with their switch + resistors
    [ICEDLeft.kicad_pcb, ICEDRight.kicad_pcb, ledmatrix.kicad_sch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]
2021-09-26 LED orientation and start routing around main mcu
    [ICEDRight.kicad_pcb]
2021-09-26 Change J-Link connector
    [ICEDRight.kicad_sch, mcu.kicad_sch]
2021-09-27 Left: Revert to SMD diodes
    [ICEDLeft.kicad_pcb, ICEDLeft.kicad_sch, ICEDRight.kicad_pcb]
2021-09-28 Left: position and start reouting SMD diodes
    [ICEDLeft.kicad_pcb]
2021-09-29 Left: more routing
    [ICEDLeft.kicad_pcb]
